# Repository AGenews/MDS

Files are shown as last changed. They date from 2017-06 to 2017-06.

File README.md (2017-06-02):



# Motion Detector Shield
A simplified microwave-based motion detector for home cage activity monitoring in mice.



MIT License

Copyright (c) [2017] [Andreas Genewsky]

Permission is hereby granted, free of charge, to any person obtaining a copy
of this software and associated documentation files (the "Software"), to deal
in the Software without restriction, including without limitation the rights
to use, copy, modify, merge, publish, distribute, sublicense, and/or sell
copies of the Software, and to permit persons to whom the Software is
furnished to do so, subject to the following conditions:

The above copyright notice and this permission notice shall be included in all
copies or substantial portions of the Software.

THE SOFTWARE IS PROVIDED "AS IS", WITHOUT WARRANTY OF ANY KIND, EXPRESS OR
IMPLIED, INCLUDING BUT NOT LIMITED TO THE WARRANTIES OF MERCHANTABILITY,
FITNESS FOR A PARTICULAR PURPOSE AND NONINFRINGEMENT. IN NO EVENT SHALL THE
AUTHORS OR COPYRIGHT HOLDERS BE LIABLE FOR ANY CLAIM, DAMAGES OR OTHER
LIABILITY, WHETHER IN AN ACTION OF CONTRACT, TORT OR OTHERWISE, ARISING FROM,
OUT OF OR IN CONNECTION WITH THE SOFTWARE OR THE USE OR OTHER DEALINGS IN THE
SOFTWARE.

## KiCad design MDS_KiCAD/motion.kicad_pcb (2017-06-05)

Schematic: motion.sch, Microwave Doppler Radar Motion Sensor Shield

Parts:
AD1: AD1; Socket_Strip_Straight_1x03
AD2: AD2; Socket_Strip_Straight_1x03
AD3: AD3; Socket_Strip_Straight_1x03
C1, C2, C3, C4, C5, C6: 22µF; C_Radial_D5_L11_P2
D1: 1N4148; Diode_DO-35_SOD27_Horizontal_RM10
D2, D3, D4, D5, D6: D; Diode_DO-35_SOD27_Horizontal_RM10
D7, D8, D9, D10, D11, D12: LED; LED-3MM
IC1, IC2, IC3: SN74LS423; DIP-16_W7.62mm_LongPads
P1: SENSOR_A; Socket_Strip_Straight_1x04
P2: SENSOR_B; Socket_Strip_Straight_1x04
P3: SENSOR_C; Socket_Strip_Straight_1x04
P4: SENSOR_D; Socket_Strip_Straight_1x04
P5: SENSOR_E; Socket_Strip_Straight_1x04
P6: SENSOR_F; Socket_Strip_Straight_1x04
Q1: TEMT6000; R_1206_HandSoldering
R1, R14, R15, R16, R17, R18, R19, R20: 10K; R_0805_HandSoldering
R2, R3, R8, R9, R10, R13: 2.2K; R_0805_HandSoldering
R4, R5, R6, R7, R11, R12: 220K; R_0805_HandSoldering
SHIELD1: MDR_SHIELD; ARDUINO_SHIELD_2

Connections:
(MISO): SHIELD1.12
(MOSI): SHIELD1.11
(RTC_SCL): SHIELD1.AD5
(RTC_SDA): SHIELD1.AD4
(SCK): SHIELD1.13
(SD_CS): SHIELD1.10
+5V: AD1.1, AD2.1, AD3.1, IC1.16, IC2.16, IC3.16, P1.1, P1.3, P2.1, P2.3, P3.1, P3.3, P4.1, P4.3, P5.1, P5.3, P6.1, P6.3, Q1.2 (C), R2.2, R3.2, R4.2, R5.2, R6.2, R7.2, R8.2, R9.2, R10.2, R11.2, R12.2, R13.2, SHIELD1.5V
AD1: AD1.3, SHIELD1.AD1
AD2: AD2.3, SHIELD1.AD2
AD3: AD3.3, SHIELD1.AD3
AMBIENT_LIGHT: Q1.1 (E), R14.1, SHIELD1.AD0
GNDREF: AD1.2, AD2.2, AD3.2, IC1.1, IC1.8, IC1.9, IC2.1, IC2.8, IC2.9, IC3.1, IC3.8, IC3.9, P1.4, P2.4, P3.4, P4.4, P5.4, P6.4, R1.2, R14.2, R15.2, R16.2, R17.2, R18.2, R19.2, R20.2, SHIELD1.GND1, SHIELD1.GND2, SHIELD1.GND3
unnamed: C1.1, IC1.15, R4.1
unnamed: C1.2, IC1.14
unnamed: C2.1, IC2.15, R5.1
unnamed: C2.2, IC2.14
unnamed: C3.1, IC1.7, R6.1
unnamed: C3.2, IC1.6
unnamed: C4.1, IC2.7, R7.1
unnamed: C4.2, IC2.6
unnamed: C5.1, IC3.15, R11.1
unnamed: C5.2, IC3.14
unnamed: C6.1, IC3.7, R12.1
unnamed: C6.2, IC3.6
unnamed: D1.1, D2.1, D3.1, D4.1, D5.1, D6.1, R1.1, SHIELD1.2
unnamed: D7.1, IC1.4
unnamed: D7.2, R2.1
unnamed: D8.1, IC2.4
unnamed: D8.2, R3.1
unnamed: D9.1, IC1.12
unnamed: D9.2, R8.1
unnamed: D10.1, IC2.12
unnamed: D10.2, R9.1
unnamed: D11.1, IC3.4
unnamed: D11.2, R10.1
unnamed: D12.1, IC3.12
unnamed: D12.2, R13.1
SENS_A: D1.2, IC1.2, P1.2, R17.1
SENS_B: D2.2, IC2.2, P2.2, R15.1
SENS_C: D3.2, IC3.2, P3.2, R16.1
SENS_D: D4.2, IC1.10, P4.2, R18.1
SENS_E: D5.2, IC2.10, P5.2, R19.1
SENS_F: D6.2, IC3.10, P6.2, R20.1
flopA: IC1.13, SHIELD1.3
flopB: IC2.13, SHIELD1.4
flopC: IC3.13, SHIELD1.5
flopD: IC1.5, SHIELD1.6
flopE: IC2.5, SHIELD1.7
flopF: IC3.5, SHIELD1.8
flopRST: IC1.3, IC1.11, IC2.3, IC2.11, IC3.3, IC3.11, SHIELD1.9

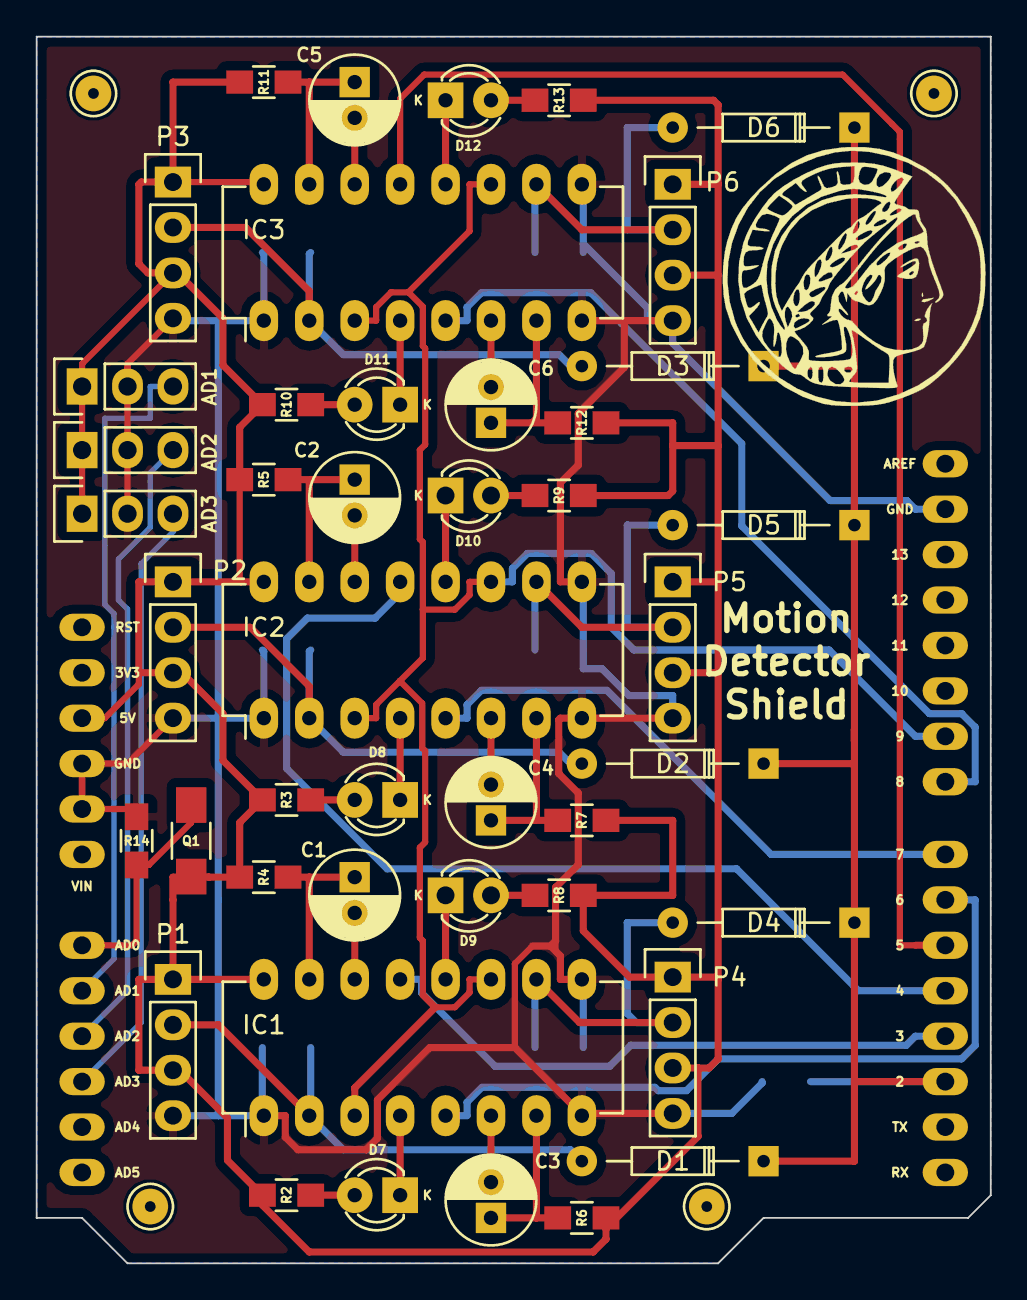
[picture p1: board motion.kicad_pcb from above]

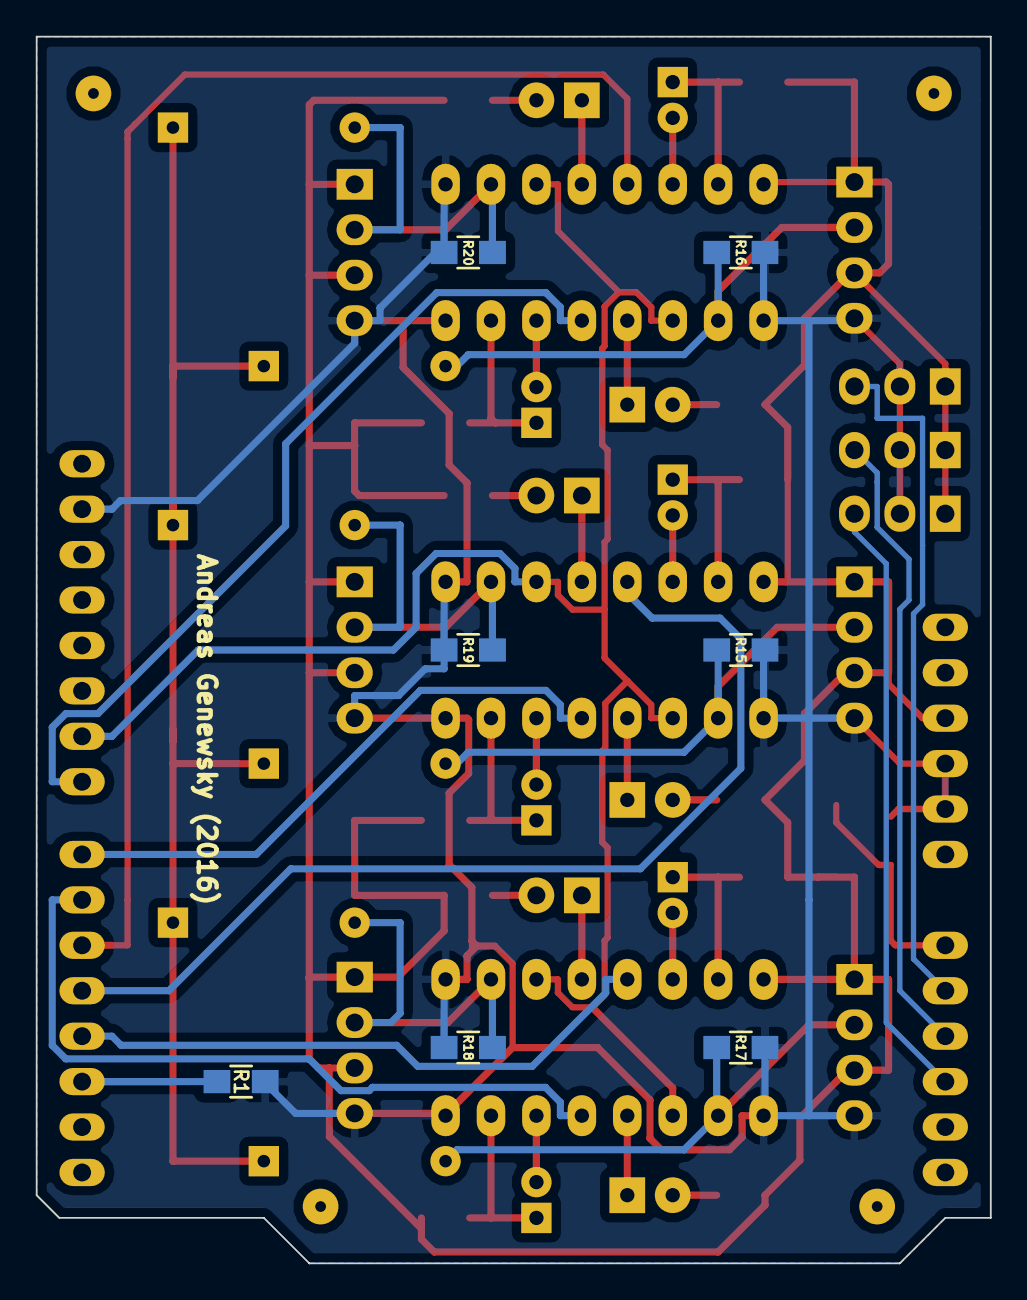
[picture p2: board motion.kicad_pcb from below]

Board: 2 copper layers, 53.3 x 68.6 mm, 52 parts (7 on the bottom side), 44 nets.

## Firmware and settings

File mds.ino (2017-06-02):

////////////////////////////////////////////////////////////////////////////////
//                 *** Motion Detector Shield Arduino Code ***                //
//                                                                            //
// This programm should be used together with Motion Detector Shield and an   // 
// Arduino Uno > Rev.3. as well as an Adafruit Data Logging Shield. Much of   // 
// the code is inspired by Adafruits excellent documentation and tutorials.   //
// See https://www.adafruit.com/product/1141                                  //
//                                                                            //
//                                                                            //  
//                            Andreas Genewsky (2017)                         //
//              Max-Planck Institute for Psychiatry, Munich, Germany          //
////////////////////////////////////////////////////////////////////////////////

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

#include <SD.h>
#include <Wire.h>
#include "RTClib.h"

#define ECHO_TO_SERIAL   1 // echo data to serial port
#define WRITE_TO_SD   1 // initialize SD and write data to SD

int flopRST = 9;  // SN74LS423 RESET Pin ... read SN74LS423 documentation
int SENS_A = 3;   // channel A 
int SENS_B = 4;   // channel B
int SENS_C = 5;   // channel C
int SENS_D = 6;   // channel D
int SENS_E = 7;   // channel E
int SENS_F = 8;   // channel F
int AMBIENT = 14; // corresponds to A0 on Arduino UNO, TEMT6000 lightsensor
int AD1 = 15;     // optional analog input
int AD2 = 16;     // optional analog input
int AD3 = 17;     // optional analog input
float lux = 0.0;  // value necessary for lux calculation
float lplux = 0.0;  // value necessary for lux calculation
int sensors[6];   // motion sensor array
volatile byte state = LOW;  // a variable which changes if motion was detected
int ledPin = 13;  // the Arduino onboard LED
int bootup = 0; // a placeholder for the time in milliseconds at bootup
unsigned int ms = 0;  // a placeholder for the milliseconds between the RTC seconds


//RTC_DS1307 RTC; // define the Real Time Clock object, use the RT which
RTC_PCF8523 RTC;  // corresponds to the one present on your board

// for the data logging shield, we use digital pin 10 for the SD cs line
const int chipSelect = 10;
// the logging file
File logfile;

void error(char *str) // the definition of an error function
{
  Serial.print("error: ");
  Serial.println(str);
  while(1);
}

// here we set the date- and timestamp the logging file
void dateTime(uint16_t* date, uint16_t* time) 
{
  DateTime now = RTC.now();
  *date = FAT_DATE(now.year(), now.month(), now.day());
  *time = FAT_TIME(now.hour(), now.minute(), now.second());
}

void setup() {  // the setup function begins

  Serial.begin(57600); // for some debugging purposes
 
  if (! RTC.begin()) { // starting the RealTimeClock (RTC)
    Serial.println("Couldn't find RTC");
    while (1);
  }
  // Here we set the clock according to the CPU Time of the programing PC
  RTC.adjust(DateTime(F(__DATE__), F(__TIME__))); 
  // If this line stays uncommented, the clock will always start from the date and
  // time when the sketch was compiled. Either you use a dedicated time setting
  // script, or you simply upload this sketch two times:
  // (1) once with the time setting line uncommented
  // (2) and second quickly afterwards with the line commented out
  // This leaves you with a slight offset, but for behavioral 
  // stduies, this might be tolerated.
  
  // immediately afterwards we get the milliseconds since bootup 
  bootup = millis(); 
  
  // no we set the INPUT & OUTPUT Pins
  pinMode(flopRST, OUTPUT);
  pinMode(SENS_A, INPUT);
  pinMode(SENS_B, INPUT);
  pinMode(SENS_C, INPUT);
  pinMode(SENS_D, INPUT);
  pinMode(SENS_E, INPUT);
  pinMode(SENS_F, INPUT);
  pinMode(AMBIENT, INPUT);
  pinMode(AD1, INPUT);
  pinMode(AD2, INPUT);
  pinMode(AD3, INPUT);
 
  attachInterrupt(0, detected, FALLING); 
  // this links a +5V voltage level at pin 2 (Arduino Interrupt Pin = pinnumber 0) 
  // to the execution of the function 'detected'
  digitalWrite(flopRST, HIGH);

#if WRITE_TO_SD
  // we initialize the SD card, and check if we can write on it
  Serial.print("Initializing SD card...");
  pinMode(chipSelect, OUTPUT);
  if (!SD.begin(chipSelect)) {
    error("Card failed, or not present");
  }
  Serial.println("card initialized.");

  // this function generates filenames with incrementing numbers
  char filename[] = "MOTION00.CSV"; 
  for (uint8_t i = 0; i < 100; i++) {
    filename[6] = i/10 + '0';
    filename[7] = i%10 + '0';
    if (! SD.exists(filename)) {
      SdFile::dateTimeCallback(dateTime);
      logfile = SD.open(filename, FILE_WRITE); 
      break;  // leave the loop!
    }
  }
  
  if (! logfile) {
    error("couldnt create file");
  }
  
  Serial.print("Logging to: ");
  Serial.println(filename);
  // the next line writes the column descriptors to the logging file
  logfile.println("MONTH,DAY,YEAR,HH,MM,SS,mmm,CH1,CH2,CH3,CH4,CH5,CH6,LUX");    
#endif WRITE_TO_SD

// in order to blank any strange behavior of the SN74LS423 we RESET all of them before we log
digitalWrite(flopRST, LOW);
digitalWrite(ledPin, HIGH);
delay(50);
digitalWrite(ledPin, LOW);
digitalWrite(flopRST, HIGH);
delay(50);

} //end of SETUP

// the loop routine runs over and over again forever:
void loop() {
  DateTime now; // here we get the time every loop
  // we calculate the light intensity in lux
  // the conversion from voltage to microamps to lux can be found in the datasheet of the TEMT6000
  lux = (analogRead(AMBIENT) * 0.9765625) * 0.1 + lplux * 0.9; 
  lplux = lux;
  now = RTC.now();
  ms = (millis()-bootup)%1000; //here we calculate the <1000 milliseconds 

  if (state == HIGH) {          // we enter this loop if an interrupt event has happend 
    detachInterrupt(0);         // ('detected function has run)
    digitalWrite(flopRST, LOW); // to avoid problems we detach the interrupts
    digitalWrite(ledPin, HIGH);

    #if ECHO_TO_SERIAL
      // we will print CommaSeparatedValues (CSV) at the Serial Monitor for:
      // MONTH,DAY,YEAR,HOUR,MINUTES,SECONDS,MILLISECONDS,CH1,CH2,CH3,CH4,CH5,CH6,LUX
      if (now.month() < 10) {
        Serial.print(0);
      } 
      Serial.print(now.month(), DEC);
      Serial.print(",");
      if (now.day() < 10) {
        Serial.print(0);
      }
      Serial.print(now.day(), DEC);
      Serial.print(",");
      Serial.print(now.year(), DEC);
      Serial.print(",");
      if (now.hour() < 10) {
        Serial.print(0);
      }
      Serial.print(now.hour(), DEC);
      Serial.print(",");
      if (now.minute() < 10) {
        Serial.print(0);
      }
      Serial.print(now.minute(), DEC);
      Serial.print(",");
      if (now.second() < 10) {
        Serial.print(0);
      }
      Serial.print(now.second(), DEC);
      Serial.print(",");
      if (ms < 10) {
        Serial.print("00");
      }
      if ( (ms >= 10) && (ms < 100) ) {
        Serial.print(0);
      }
      Serial.print(ms, DEC);
      
      for (int i = 0; i < 6; i++) {
        Serial.print(",");
        Serial.print(sensors[i]);
      }
      Serial.print(',');
      Serial.println(lux, 1);
    #endif ECHO_TO_SERIAL

    #if WRITE_TO_SD
       // we will write some CommaSeparatedValues (CSV) to the logfile for:
      // MONTH,DAY,YEAR,HH,MM,SS,mmm,CH1,CH2,CH3,CH4,CH5,CH6,LUX
      if (now.month() < 10) {
        logfile.print(0);
      }
      logfile.print(now.month(), DEC);
      logfile.print(",");
      if (now.day() < 10) {
        logfile.print(0);
      }
      logfile.print(now.day(), DEC);
      logfile.print(",");
      logfile.print(now.year(), DEC);
      logfile.print(",");
      if (now.hour() < 10) {
        logfile.print(0);
      }
      logfile.print(now.hour(), DEC);
      logfile.print(",");
      if (now.minute() < 10) {
        logfile.print(0);
      }
      logfile.print(now.minute(), DEC);
      logfile.print(",");
      if (now.second() < 10) {
        logfile.print(0);
      }
      logfile.print(now.second(), DEC);
      logfile.print(",");
      if (ms < 10) {
        logfile.print("00");
      }
      if ( (ms >= 10) && (ms%1000 < 100) ) {
        logfile.print(0);
      }
      logfile.print(ms, DEC);
      for (int i = 0; i < 6; i++) {
        logfile.print(",");
        logfile.print(sensors[i]);
        sensors[i] = 0;
      }
      logfile.print(',');
      logfile.println(lux, 1);

      // flush() actually writes the data to the SD card and is very important
      logfile.flush();
    #endif WRITE_TO_SD

    // here we basically write 0's in our sensor array to be able to store new events 
    sensors[6];

    // than we RESET the SN74LS423 IC's
    delay(10);
    digitalWrite(ledPin, LOW);
    digitalWrite(flopRST, HIGH);
    delay(10);
    // now we arm our interrupt routine again
    state = LOW; 
    attachInterrupt(0, detected, FALLING);
  }
}

void detected() {
  // the interrupt routine simply checks all the sensor ports if something happend (0-5V)
  if (state == LOW) {
    detachInterrupt(0);
    sensors[0] = digitalRead(SENS_A);
    sensors[1] = digitalRead(SENS_B);
    sensors[2] = digitalRead(SENS_C);
    sensors[3] = digitalRead(SENS_D);
    sensors[4] = digitalRead(SENS_E);
    sensors[5] = digitalRead(SENS_F);
    state = HIGH;

    int sum = 0;
    for (int i = 0; i < 6; i++) {
      sum = sum + sensors[i];
    }
    if (sum == 0) {
      state = LOW;
      attachInterrupt(0, detected, FALLING);
    }
  }
}

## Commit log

2016-08-30 Added Gerber files Rev0.2
    [motion-B.Cu.gbl, motion-B.Mask.gbs, motion-B.SilkS.gbo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]
2016-08-30 Added Arduino Code
2017-06-05 Uploaded KiCAD design files.
    [motion.kicad_pcb, motion.sch]
2017-06-05 Uploaded RAW data.
    [LAB_CD1_raw_60min.CSV, clock_raw.CSV]
2017-06-05 Update motion_analysis.py
    I've put the print (...) in line 88 in brackets, as this seems to avoid throwing an error before the usage commands appear.
2017-08-18 Update motion_analysis.py
    Now allows to use millisecond bins.
